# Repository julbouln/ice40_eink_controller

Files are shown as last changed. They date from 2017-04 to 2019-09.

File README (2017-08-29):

FPGA & STM32F0 driven EINK controller

- Final FPGA board: https://oshpark.com/shared_projects/rBoQ8bop
- The links on the Kitnic page make ordering the parts easier: https://kitnic.it/boards/github.com/julbouln/ice40_eink_controller/
- ifusb companion: https://github.com/julbouln/ifusb

Prototype:
- OLIMEX iCE40HX1K-EVB (https://www.olimex.com/Products/FPGA/iCE40/iCE40HX1K-EVB/open-source-hardware)
- NUCLEO-F042K6 (http://www.st.com/content/st_com/en/products/evaluation-tools/product-evaluation-tools/mcu-eval-tools/stm32-mcu-eval-tools/stm32-mcu-nucleo/nucleo-f042k6.html)
- TPS65185EVM (http://www.ti.com/tool/tps65185evm)
- ED060SC7 Kindle 3 EINK screen (http://www.ebay.com/sch/i.html?_from=R40&_trksid=m570.l1313&_nkw=ED060SC7&_sacat=0)
- custom EINK connector board (https://oshpark.com/shared_projects/I7bqOkZB)

Project tree:
- controller/ EINK controller verilog icestorm project
- hardware/ custom ice40 + ED060SC7 connector board
- utils/ misc utilities, including dumper for various reverse engineered waveform file formats
- utils/ifusb/ ifusb host driver

References:
- http://essentialscrap.com/eink/
- http://www.eevblog.com/forum/microcontrollers/interfacing-epd-%28e-ink%29-display-from-kindle-anyone-tried/

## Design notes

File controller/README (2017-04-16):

ice40 eink verilog controller

Notes

Yosys 0.6 needed, because it seems there is a bug related to BRAM with current version https://github.com/cliffordwolf/yosys/issues/335

About performances

Ifusb 12Mhz SPI
1s : 0.25s WRITE + 0.75s DRAW(at 40ns)
0.75s : 0.25s WRITE + 0.50s DRAW(at 20ns)

Full framebuffer write: 800x600/4 = 120000 bytes
At 12Mhz, SPI bandwidth should be around 9Mbs, so theoricaly we should have a write time of ~0.1s but ifusb will introduce latency to SPI because of USB (120000/64 = 1875 bulk packets)

SPI protocol

Command 		Hex		Description
EINK_PING 		0x01	Ping the chip
EINK_STATUS 	0x02	Get current screen status
EINK_WRITE 		0x03	Write data to framebuffer
EINK_DRAW 		0x04	Draw framebuffer to screen
EINK_SET_MODE 	0x05	Set current draw mode

EINK_PING
For testing purpose, simply ping the chip, should return the data send
0x01 0xAA -> 0xAA

EINK_STATUS
Get screen status
0x02 STATUS

Where STATUS is:
bits 7-3: reserved
bits 2-1: current drawing mode (see EINK_SET_MODE)
bit 0: ready or not

EINK_WRITE
Write pixels data to chip framebuffer
0x03 followed by 800x600/4 = 120000 bytes representing pixels in

EINK_DRAW
Actually draw current framebuffer on panel
0x04 0x00

EINK_SET_MODE
Set drawing mode
MODE_CLEAR 	0x00 Clear the screen to white
MODE_DRAW 	0x01 GC4 mode

Waveform hex format

x = color
y = phase

Eink ED06SC7 display signals:
	gmode/mode1: output mode
	cl: source clock
	ckv: gate clock
	spv (start pulse gate): high->low start gate sequence
	sph/xstl (start pulse source): high->low start source sequence
	le (latch enable): low->high load data
	oe (output enable): high->low output data
	d[7:0]: data

source:
     ┌─┐  ┌─┐  ┌─┐  ┌─┐  ┌─┐
cl  ─┘ └──┘ └──┘ └──┘ └──┘ └─ 50ns cycle
    ───┐    ┌────────────────
sph    └────┘
                    ┌─┐           
le  ────────────────┘ └──────
                                                 
d[7:0] __DD___DD___DD___

gate:
     ┌─┐  ┌─┐  ┌─┐  ┌─┐  ┌─┐
ckv ─┘ └──┘ └──┘ └──┘ └──┘ └─ min L 0.5 us
    ──┐    ┌─────────────────
spv   └────┘

References:
http://essentialscrap.com/eink/waveforms.html
http://www.eevblog.com/forum/microcontrollers/interfacing-epd-%28e-ink%29-display-from-kindle-anyone-tried/

TODO
- 20ns operation works, but seems to be a bit buggy
- add SPI command for setting waveform
- 2-bits/4 colors only, must support 4-bits/16 colors (see next point)
- refactor sram/waveform : 

Instead of keeping flipping 2-bits pixel in framebuffer (old pix and new pix) and calculating panel 2-bits signal at drawing step, keep only old framebuffer in 4-bits form in highest part of sram (start at 128k) and calculate 2-bits signal at write step and keep it in lowest part of sram. With this method, we can achieve best performance (20ns operations at drawing), SPI bandwidth being limited by itself (8 cycles for sck 12Mhz) we have more timing room at this step. 

Read the old value from sram, calculate the signal, and write the result to sram should take 4 cycles:
- receive new pixel + set address of old pixel
- read old pixel + set it to waveform calculator
- read calculated result + set address and data to write calculation
- wait data to be writen

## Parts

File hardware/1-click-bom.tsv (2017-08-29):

References | Qty | Description | Manufacturer | MPN | Manufacturer | MPN | Manufacturer | MPN | Manufacturer | MPN | Manufacturer | MPN | Digikey | Mouser | RS | Newark | Farnell
C1, C2, C3, C4 | 4 | 10uF 3216 | KEMET | B45196H2106K109 | AVX | NOSA106M006R0800 | AVX | TAJA106K016RNJ | Vishay | 293D106X9010A2TE3 | AVX | TAJA106K010RNJ | 478-1654-1-ND | 581NOSA106M006R0800 | 4647619 | 65K2813 | 1432318
C11, C22 | 2 | 4.7uF 0603 25V | Murata | GRM188R61E475KE11D | Murata | GRM188R61E475KE15D | Yageo | CC0603KRX5R8BB475 | Murata | GRT188R61E475KE13D | TDK | C1608X5R1E475K080AC | 311-3487-1-ND | 81GRM188R61E475KE1D | 8151386 | 68X2788 | 2672159
C5, C10, C21, C25, C26, C27, C28, C29, C30, C31, C32, C33, C34, C35, C36, C37, C39, C40, C41, C42, C43 | 21 | 100nF 0603 | Yageo | CC0603KRX7R9BB104 | Murata | GRM188R71H104KA93D | Samsung | CL10B104KB8NNNC | AVX | 06033C104KAT2A |  |  | 478-3714-1-ND | 603CC603KRX7R9BB104 | 7235676 | 68R4788 | 1362556
C6, C13, C14 | 3 | 10uF 0805 | Murata | GRM21BR61C106KE15L |  |  |  |  |  |  |  |  | 490-3886-1-ND | 81GRM21BR61C106KE15 | 7236039 | 35R0687 | 1762635
C7, C8, C12, C15, C16, C17, C18, C19, C23, C24 | 10 | 4.7uF 0805 16V | Murata | GRM21BR61E475KA12L |  |  |  |  |  |  |  |  | 490-3335-1-ND | 81GRM21BR61E475KA12 | 7236057 | 24R6340 | 1735529
C9, C20 | 2 | 10nF 0603 | Murata | GRM188R71H103KA01D | Yageo | CC0603KRX7R9BB103 |  |  |  |  | AVX | 0201ZD103KAT2A | 311-1085-6-ND | 81GRM39X103K50D | 2040779 | 38K1669 | 722236RL
D1 | 1 | DIODE SOD-123-2 | MCC | 1N4148W-TP | Diodes Inc. | 1N4148WS-7-F |  |  |  |  |  |  | 1N4148WTPMSCT-ND | 8331N4148WTP | 7384737 | 51T5044 | 1843678
D4, D7 | 2 | MBR130T3G SOD123 | ON Semiconductor | MBR130T3G | Diodes Inc. | B130LAW-7-F |  |  |  |  |  |  | B130LAW-FDICT-ND | 863MBR130T3G | 7815635 | 42K0004 | 1858617
D6, D8 | 2 | BAV99 SOT23 | ON Semiconductor | BAV99LT1G | ON Semiconductor | BAV99LT3G |  |  |  |  |  |  | BAV99LT1GOSCT-ND | 863BAV99LT1G | 1249957 | 10N9382 | 2533389
J1 | 1 | Socket (0.4mm pitch, 34-pin, Ni-barrier) | Panasonic | AXT334124 |  | ED060SC7 |  |  |  |  |  |  | 255-3300-1-ND | 769AXT334124 |  | 29X3301
J2 | 1 | Connector, right angle, surface mount, female, 16 contacts, 2 rows, 2.54mm | Würth Elektronik | 610116249221 |  |  |  |  |  |  |  |  | 732-6082-1-ND | 710610116249221 |  |  | 2470746
L1 | 1 | 4.7uH 20% 1MHz Ferrite 1.1A 1008 | Samsung | CIG22L4R7MNE | Taiyo Yuden | CKP2520V4R7M-T | Murata | LQM2HPN4R7MG0L | Abracon | ASMPH-1008-4R7M-T | Bourns | CVH252009-4R7M | 1276-6213-1-ND | 963CKP2520V4R7MT | 7867131 | 24W0975 | 2118126
L2, L3, L4 | 3 | 2.2uH 20% 1MHz Ferrite 1.3A 1008 | Samsung | CIG22L2R2MNE | NIC Components | NFP1008M2R2TR130F | Murata | LQM2HPN2R2MG0L | Bourns | CVH252009-2R2M |  |  | 1276-6211-1-ND | 652CVH2520092R2M | 7867112 | 24W0973 | 2217694
OSC1 | 1 | 100Mhz 7mm x 5mm | Ecliptek | EC2700TTS-100.000M TR | Ecliptek | EC2700ETTS-100.000M TR | Euroquartz | 3EQHM57-ET-100.000R-C1.5 | Ecliptek | EC2645TTS-100.000M TR | AVX | KC7050A100.000C30E00 | 478-6145-1-ND | 581KC7050A100.0C30 |  | 05N0946 | 1641083
R10 | 1 | 47k5 0603 | Yageo | RC0603FR-0747K5L | Yageo | RT0603FRE0747K5L | Panasonic | ERA-3ARB4752V | TE Connectivity | 8-1614353-4 | TE Connectivity / Neohm | CPF0603B47K5E1 | 311-47.5KHRCT-ND | 603RC0603FR0747K5L | 1228887 | 68R0096 | 2312067
R12 | 1 | 52k3 0603 | Panasonic | ERA3ARB5232V | Yageo | RC0603FR-0752K3L | Vishay Dale | CRCW060352K3FKTA | Panasonic | ERA-3AEB5232V |  |  | P52.3KDBCT-ND | 71CRCW060352.3K | 7088940P | 52K8601 | 2094621
R23, RD5, RD1, RD2, RD3, RD4 | 6 | 0 Ohm 0603 | Vishay | CRCW06030000Z0EAHP | Vishay | CRCW06030000Z0EA | Panasonic | ERJ-3GEY0R00V |  |  |  |  | P0.0GCT-ND | 667ERJ3GEY0R00V | 8206736 | 65T8702 | 1469739
R27 | 1 | 43k 0603 | Panasonic | ERA3APB433V | Vishay | CRCW060343K0FKEA | Panasonic | ERA3AEB433V | Panasonic | ERJP03F4302V | Yageo | RC0603JR-0743KL | 311-43.2KHRDKR-ND | 603RC0603JR0743KL | 6790386 | 52K8524 | 1892846
R3, R5, R6 | 3 | 10k 0603 | Vishay | CRCW060310K0FKEA | Vishay | CRCW060310K0FKEAHP | Panasonic | ERJ-3EKF1002V |  |  |  |  | 311-10.0KHRCT-ND | 71CRCW060310KE3 | 8206742 | 68R2991 | 1469748
R4, R13 | 2 | 22R 0603 | Yageo | RC0603JR-0722RL |  |  |  |  |  |  |  |  | 311-22GRCT-ND | 603RC0603JR0722RL |  | 68R0168 | 9233172
R7 | 1 | 2.2k 0603 1% | Vishay | MCT06030C2201FP500 | Yageo | RC0603FR-072K2L | Panasonic | ERA3AEB222V |  |  |  |  | 311-2.20KHRCT-ND | 603RC0603FR072K2L | 566806P | 68R0064 | 1577611
R9, R11 | 2 | 1M 0603 | Vishay | CRCW06031M00FKEA | Yageo | RC0603FR-071ML | Vishay Dale | CRCW06031M00FKEAHP | Panasonic | ERJ-3EKF1004V |  |  | 541-1.00MHCT-ND | 603RC0603FR071ML | 8206786 | 64R5311 | 1469746
U1 | 1 | TPS65185RSLR | Texas Instruments | TPS65185RSLR | Texas Instruments | TPS65185SRGZR | Texas Instruments | TPS651851RSLT |  |  |  |  | 296-29565-1-ND | 595TPS651851RSLT |  | 87X2294
U2 | 1 |  | Texas Instruments | LM3671MF-1.2/NOPB |  |  |  |  |  |  |  |  | LM3671MF-1.2/NOPBCT-ND | 926LM3671MF1.2NOPB |  | 41K4937 | 1685653
U3 | 1 |  | Texas Instruments | LM3671MF-3.3/NOPB |  |  |  |  |  |  |  |  | LM3671MF-3.3/NOPBCT-ND | 926LM3671MF3.3NOPB | 7615876P | 79K7839 | 1685767
U5 | 1 | SPI FLASH SOIC8 1Mbit | Microchip | SST25VF010A-33-4I-SAE | Microchip | SST25VF010A-33-4C-SAE | Silicon Storage Tech | SST25VF010A |  |  |  |  | SST25VF010A-33-4I-SAE-ND | 80425VF010A3CSAE | 7238726 | 54M1121 | 1368686
U6 | 1 |  | Lattice Semiconductor | ICE40HX1K-VQ100 |  |  |  |  |  |  |  |  | 220-1567-ND | 842ICE40HX1KVQ100 | 7720045P |  | 2362850
U7 | 1 | IS61WV2561 | Samsung | K6R4016V1DND | ISSI | IS61WV25616BLL-10BLI-TR | ISSI | IS61WV25616BLL-10TLI-TR | ISSI | IS61WV25616BLL-10BLI |  |  | 706-1104-ND | 87061WV25616BLL10BLI |  | 55M7806

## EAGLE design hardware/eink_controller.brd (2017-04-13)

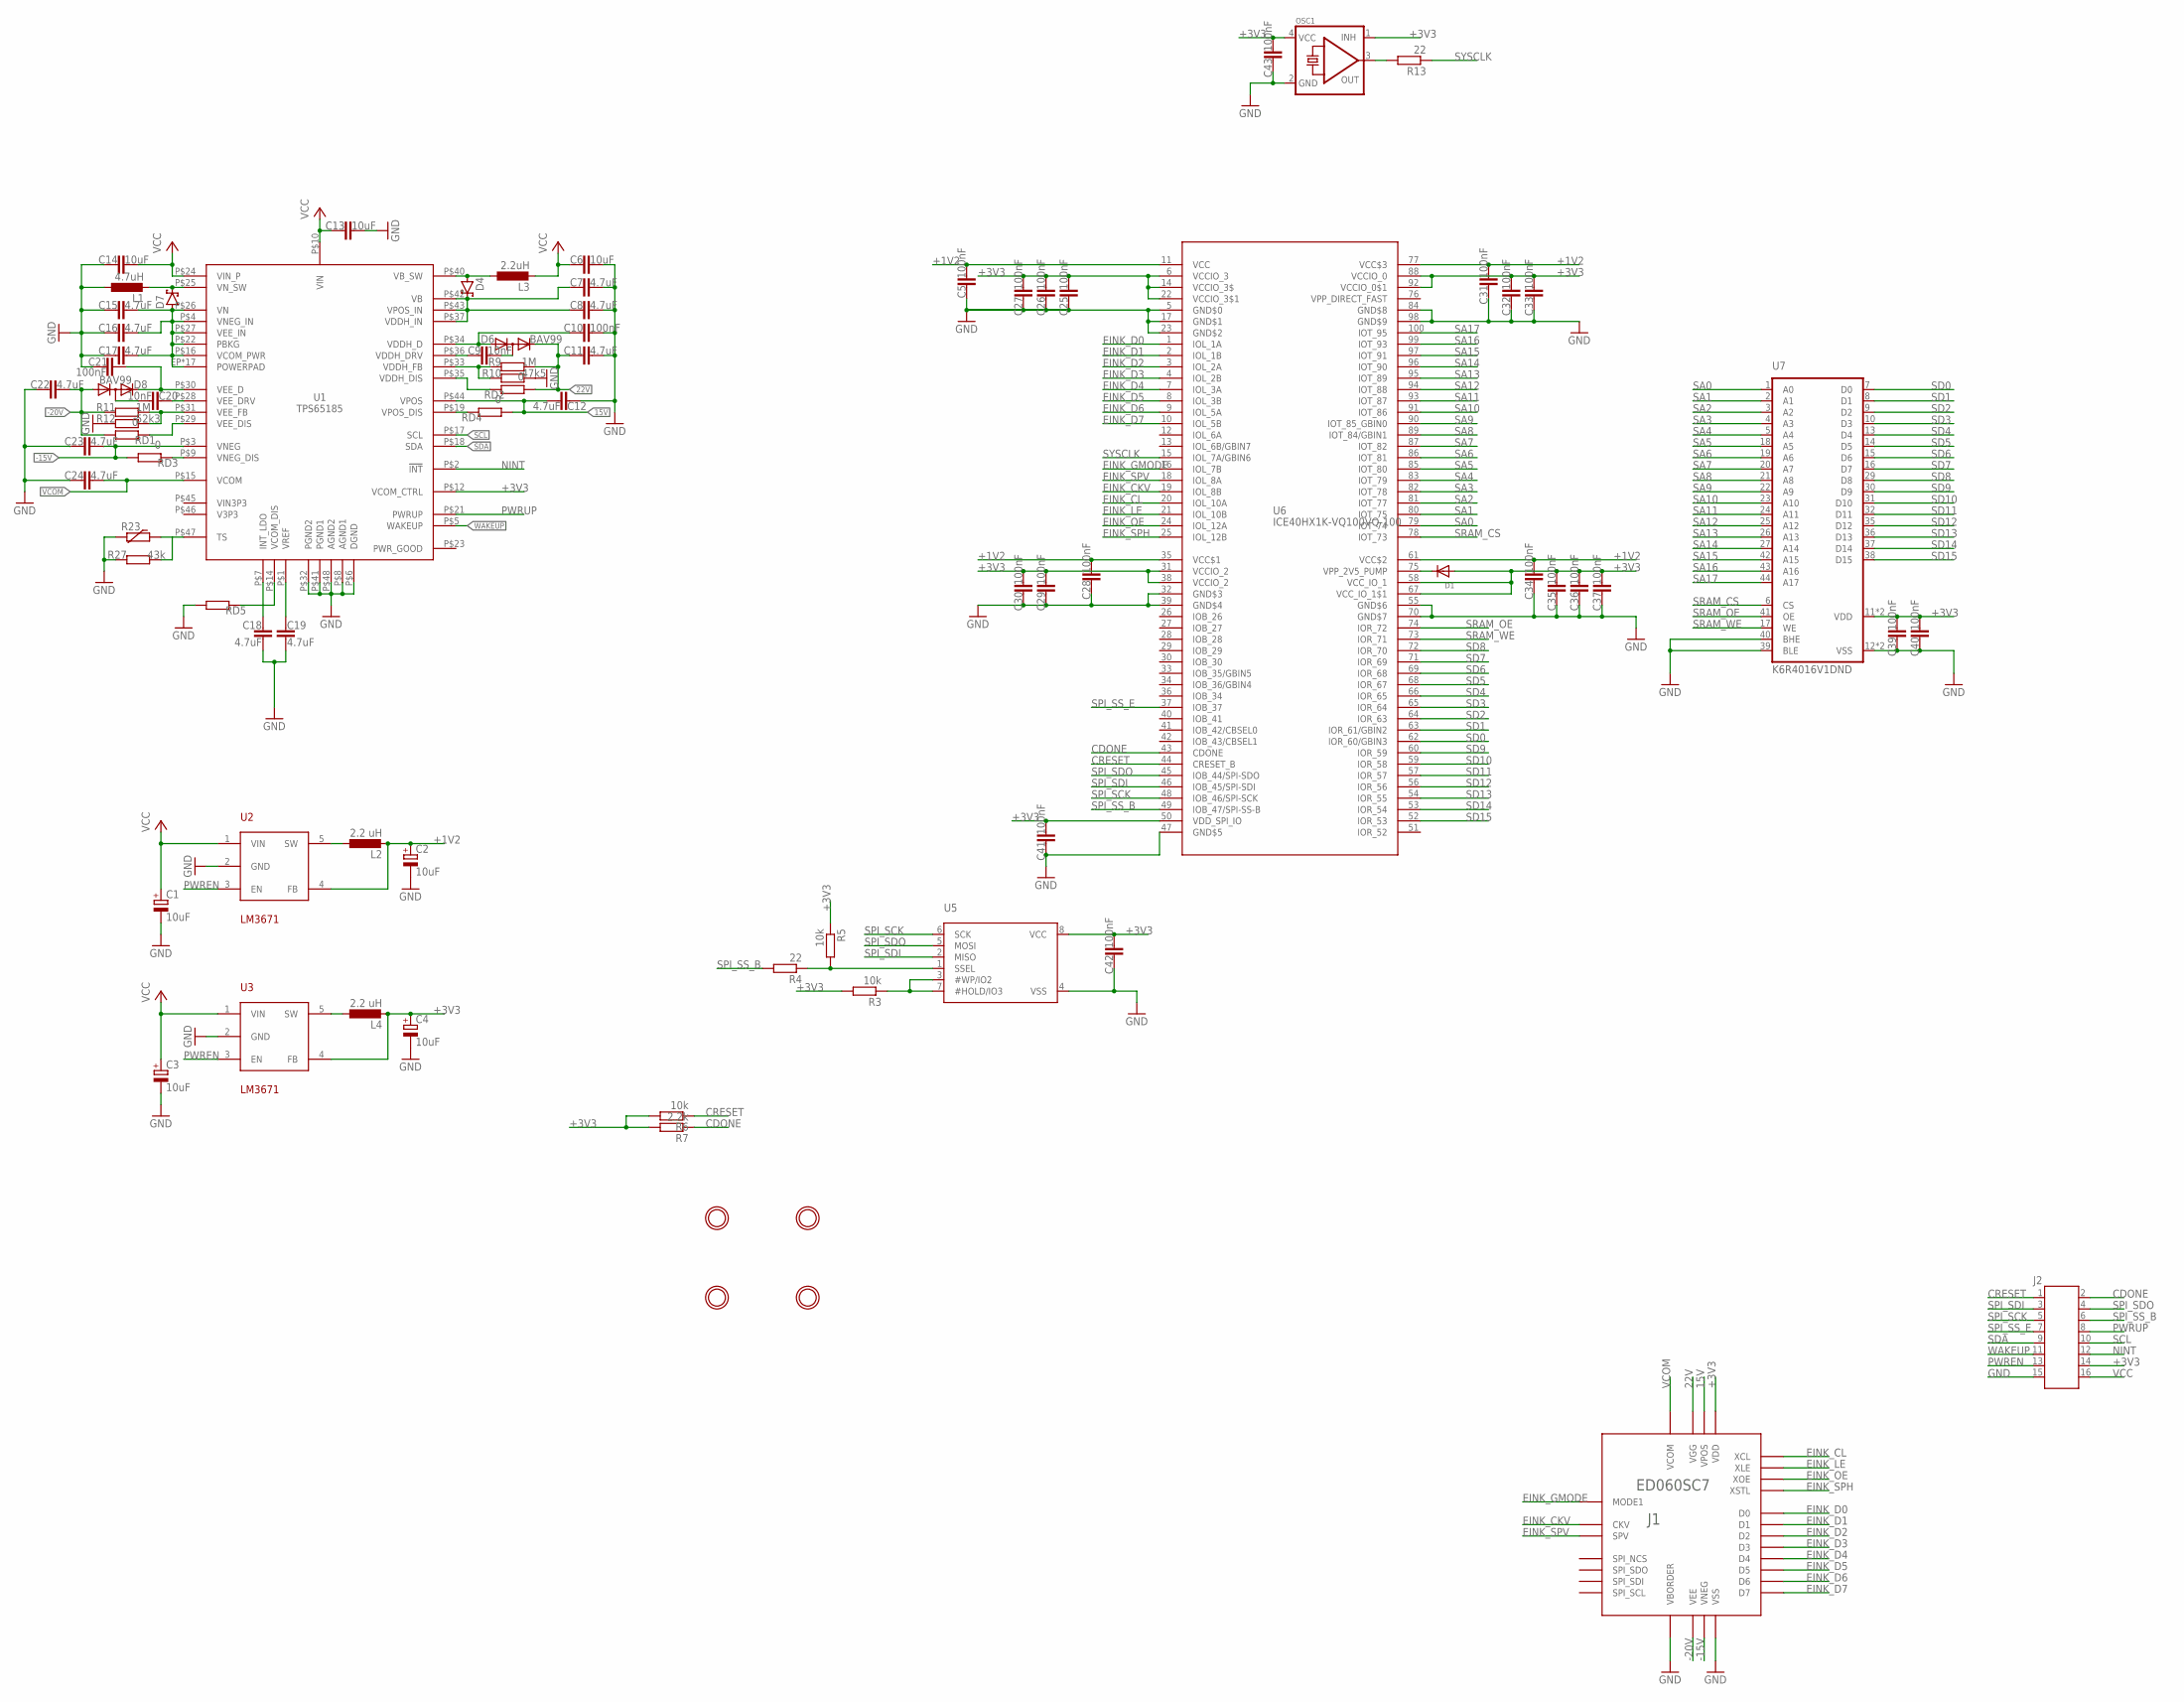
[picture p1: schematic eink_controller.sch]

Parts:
C1, C2, C3, C4: 10uF; A/3216-18R
C5, C10, C21, C25, C26, C27, C28, C29, C30, C31, C32, C33, C34, C35, C36, C37, C39, C40, C41, C42, C43: 100nF; C0603K
C6, C13, C14: 10uF; C0805K
C7, C8, C12, C15, C16, C17, C18, C19, C23, C24: 4.7uF; C0805K
C9, C20: 10nF; C0603K
C11, C22: 4.7uF; C0603K
D1: DIODESOD-123; SOD-123
D4, D7: MBR130T3G; SOD123
D6, D8: BAV99; SOT23
J1: ED060SC7; AXT334124
J2: 610116249221
L1: 4.7uH; L2825P
L2, L4: 2.2 uH; L2825P
L3: 2.2uH; L2825P
OSC1: OSCILLATOR; OSC_7X5MM
R3, R5, R6: 10k; R0603
R4, R13: 22; R0603
R7: 2.2k; R0603
R9, R11: 1M; R0603
R10: 47k5; R0603
R12: 52k3; R0603
R23: R-EU_R0603; R0603
R27: 43k; R0603
RD1, RD2, RD3, RD4: 0; R0603
RD5: R-EU_R0603; R0603
U1: TPS65185; VQFN48
U2, U3: LM3671; SOT23-5
U5: SPIFLASH_SOIC8208MIL; SOIC8_208MIL
U6: ICE40HX1K-VQ100VQ-100; TQFP100
U7: K6R4016V1DND; TSOP44-II
U$1, U$2, U$3, U$4: MOUNTINGHOLE2.0; MOUNTINGHOLE_2.0_PLATED

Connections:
15V: C12.2, J1.P$2 (VPOS), J1.P$4 (VPOS), RD4.1, U1.P$44 (VPOS)
22V: C11.1, D6.2 (C), J1.P$25 (VGG), R9.2, RD2.1
+1V2: C2.+, C5.2, C28.2, C31.2, C34.2, L2.2, U2.4 (FB), U6.11 (VCC), U6.35 (VCC$1), U6.61 (VCC$2), U6.77 (VCC$3)
+3V3: C4.+, C25.2, C26.2, C27.2, C29.2, C30.2, C32.2, C33.2, C35.2, C36.2, C37.2, C39.2, C40.2, C41.2, C42.2, C43.2, D1.A, J1.P$5 (VDD), J1.P$7 (VDD), J2.14, L4.2, OSC1.1 (INH), OSC1.4 (VCC), R3.2, R5.1, R6.2, R7.2, U1.P$12 (VCOM_CTRL), U3.4 (FB), U5.8 (VCC), U6.6 (VCCIO_3), U6.14 (VCCIO_3$), U6.22 (VCCIO_3$1), U6.31 (VCCIO_2), U6.38 (VCCIO_2), U6.50 (VDD_SPI_IO), U6.58 (VCC_IO_1), U6.67 (VCC_IO_1$1), U6.88 (VCCIO_0), U6.92 (VCCIO_0$1), U7.11 (VDD), U7.33 (VDD)
-15V: C23.2, J1.P$1 (VNEG), J1.P$3 (VNEG), RD3.2, U1.P$3 (VNEG)
-20V: C22.2, D8.1 (A), J1.P$27 (VEE), J1.P$29 (VEE), R11.1, RD1.2
CDONE: J2.2, R7.1, U6.43 (CDONE)
CRESET: J2.1, R6.1, U6.44 (CRESET_B)
EINK_CKV: J1.P$28 (CKV), U6.19 (IOL_8B)
EINK_CL: J1.P$9 (XCL), U6.20 (IOL_10A)
EINK_D0: J1.P$13 (D0), U6.1 (IOL_1A)
EINK_D1: J1.P$14 (D1), U6.2 (IOL_1B)
EINK_D2: J1.P$15 (D2), U6.3 (IOL_2A)
EINK_D3: J1.P$16 (D3), U6.4 (IOL_2B)
EINK_D4: J1.P$17 (D4), U6.7 (IOL_3A)
EINK_D5: J1.P$18 (D5), U6.8 (IOL_3B)
EINK_D6: J1.P$19 (D6), U6.9 (IOL_5A)
EINK_D7: J1.P$20 (D7), U6.10 (IOL_5B)
EINK_GMODE: J1.P$26 (MODE1), U6.16 (IOL_7B)
EINK_LE: J1.P$10 (XLE), U6.21 (IOL_10B)
EINK_OE: J1.P$11 (XOE), U6.24 (IOL_12A)
EINK_SPH: J1.P$12 (XSTL), U6.25 (IOL_12B)
EINK_SPV: J1.P$30 (SPV), U6.18 (IOL_8A)
GND: C1.-, C2.-, C3.-, C4.-, C5.1, C6.2, C7.2, C8.2, C10.2, C11.2, C12.1, C13.2, C14.1, C15.1, C16.1, C17.1, C18.1, C19.1, C21.1, C22.1, C23.1, C24.1, C25.1, C26.1, C27.1, C28.1, C29.1, C30.1, C31.1, C32.1, C33.1, C34.1, C35.1, C36.1, C37.1, C39.1, C40.1, C41.1, C42.1, C43.1, J1.P$6 (VSS), J1.P$8 (VSS), J1.P$31 (VSS), J1.P$32 (VBORDER), J2.15, L1.1, OSC1.2 (GND), R10.2, R12.1, R23.1, R27.1, RD5.2, U1.P$6 (DGND), U1.P$8 (AGND1), U1.P$32 (PGND2), U1.P$41 (PGND1), U1.P$48 (AGND2), U2.2 (GND), U3.2 (GND), U5.4 (VSS), U6.5 (GND$0), U6.17 (GND$1), U6.23 (GND$2), U6.32 (GND$3), U6.39 (GND$4), U6.47 (GND$5), U6.55 (GND$6), U6.70 (GND$7), U6.84 (GND$8), U6.98 (GND$9), U7.12 (VSS), U7.34 (VSS), U7.39 (BLE), U7.40 (BHE)
unnamed: RD5.1, U1.P$14 (VCOM_DIS)
unnamed: L4.1, U3.5 (SW)
unnamed: R3.1, U5.3 (#WP/IO2), U5.7 (#HOLD/IO3)
unnamed: OSC1.3 (OUT), R13.2
unnamed: D4.2 (A), L3.1, U1.P$40 (VB_SW)
unnamed: D1.C, U6.75 (VPP_2V5_PUMP)
unnamed: L2.1, U2.5 (SW)
unnamed: R4.1, R5.2, U5.1 (SSEL)
unnamed: C7.1, C8.1, D4.1 (C), U1.P$37 (VDDH_IN), U1.P$42 (VB), U1.P$43 (VPOS_IN)
unnamed: C10.1, D6.1 (A), U1.P$34 (VDDH_D)
unnamed: C9.1, U1.P$36 (VDDH_DRV)
unnamed: C9.2, D6.3 (AC)
unnamed: R9.1, R10.1, U1.P$33 (VDDH_FB)
unnamed: C20.2, D8.3 (AC)
unnamed: D7.1 (C), L1.2, U1.P$25 (VN_SW)
unnamed: C15.2, C16.2, C17.2, D7.2 (A), U1.EP (POWERPAD), U1.EP1 (POWERPAD), U1.EP2 (POWERPAD), U1.EP3 (POWERPAD), U1.EP4 (POWERPAD), U1.EP5 (POWERPAD), U1.EP6 (POWERPAD), U1.EP7 (POWERPAD), U1.EP8 (POWERPAD), U1.EP9 (POWERPAD), U1.EP10 (POWERPAD), U1.EP11 (POWERPAD), U1.EP12 (POWERPAD), U1.EP13 (POWERPAD), U1.EP14 (POWERPAD), U1.EP15 (POWERPAD), U1.EP16 (POWERPAD), U1.P$4 (VNEG_IN), U1.P$16 (VCOM_PWR), U1.P$22 (PBKG), U1.P$26 (VN), U1.P$27 (VEE_IN)
unnamed: C18.2, U1.P$7 (INT_LDO)
unnamed: C19.2, U1.P$1 (VREF)
unnamed: C21.2, D8.2 (C), U1.P$30 (VEE_D)
unnamed: RD3.1, U1.P$9 (VNEG_DIS)
unnamed: C20.1, U1.P$28 (VEE_DRV)
unnamed: R11.2, R12.2, U1.P$31 (VEE_FB)
unnamed: RD1.1, U1.P$29 (VEE_DIS)
unnamed: RD4.2, U1.P$19 (VPOS_DIS)
unnamed: RD2.2, U1.P$35 (VDDH_DIS)
unnamed: R23.2, R27.2, U1.P$47 (TS)
NINT: J2.12, U1.P$2 (!INT)
PWREN: J2.13, U2.3 (EN), U3.3 (EN)
PWRUP: J2.8, U1.P$21 (PWRUP)
SA0: U6.79 (IOT_74), U7.1 (A0)
SA1: U6.80 (IOT_75), U7.2 (A1)
SA2: U6.81 (IOT_77), U7.3 (A2)
SA3: U6.82 (IOT_78), U7.4 (A3)
SA4: U6.83 (IOT_79), U7.5 (A4)
SA5: U6.85 (IOT_80), U7.18 (A5)
SA6: U6.86 (IOT_81), U7.19 (A6)
SA7: U6.87 (IOT_82), U7.20 (A7)
SA8: U6.89 (IOT_84/GBIN1), U7.21 (A8)
SA9: U6.90 (IOT_85_GBIN0), U7.22 (A9)
SA10: U6.91 (IOT_86), U7.23 (A10)
SA11: U6.93 (IOT_87), U7.24 (A11)
SA12: U6.94 (IOT_88), U7.25 (A12)
SA13: U6.95 (IOT_89), U7.26 (A13)
SA14: U6.96 (IOT_90), U7.27 (A14)
SA15: U6.97 (IOT_91), U7.42 (A15)
SA16: U6.99 (IOT_93), U7.43 (A16)
SA17: U6.100 (IOT_95), U7.44 (A17)
SCL: J2.10, U1.P$17 (SCL)
SD0: U6.62 (IOR_60/GBIN3), U7.7 (D0)
SD1: U6.63 (IOR_61/GBIN2), U7.8 (D1)
SD2: U6.64 (IOR_63), U7.9 (D2)
SD3: U6.65 (IOR_64), U7.10 (D3)
SD4: U6.66 (IOR_65), U7.13 (D4)
SD5: U6.68 (IOR_67), U7.14 (D5)
SD6: U6.69 (IOR_68), U7.15 (D6)
SD7: U6.71 (IOR_69), U7.16 (D7)
SD8: U6.72 (IOR_70), U7.29 (D8)
SD9: U6.60 (IOR_59), U7.30 (D9)
SD10: U6.59 (IOR_58), U7.31 (D10)
SD11: U6.57 (IOR_57), U7.32 (D11)
SD12: U6.56 (IOR_56), U7.35 (D12)
SD13: U6.54 (IOR_55), U7.36 (D13)
SD14: U6.53 (IOR_54), U7.37 (D14)
SD15: U6.52 (IOR_53), U7.38 (D15)
SDA: J2.9, U1.P$18 (SDA)
SPI_SCK: J2.5, U5.6 (SCK), U6.48 (IOB_46/SPI-SCK)
SPI_SDI: J2.3, U5.2 (MISO), U6.46 (IOB_45/SPI-SDI)
SPI_SDO: J2.4, U5.5 (MOSI), U6.45 (IOB_44/SPI-SDO)
SPI_SS_B: J2.6, R4.2, U6.49 (IOB_47/SPI-SS-B)
SPI_SS_E: J2.7, U6.37 (IOB_37)
SRAM_CS: U6.78 (IOT_73), U7.6 (CS)
SRAM_OE: U6.74 (IOR_72), U7.41 (OE)
SRAM_WE: U6.73 (IOR_71), U7.17 (WE)
SYSCLK: R13.1, U6.15 (IOL_7A/GBIN6)
VCC: C1.+, C3.+, C6.1, C13.1, C14.2, J2.16, L3.2, U1.P$10 (VIN), U1.P$24 (VIN_P), U2.1 (VIN), U3.1 (VIN)
VCOM: C24.2, J1.P$21 (VCOM), J1.P$23 (VCOM), U1.P$15 (VCOM)
VPP_DIRECT_FAST: U6.76 (VPP_DIRECT_FAST)
WAKEUP: J2.11, U1.P$5 (WAKEUP)

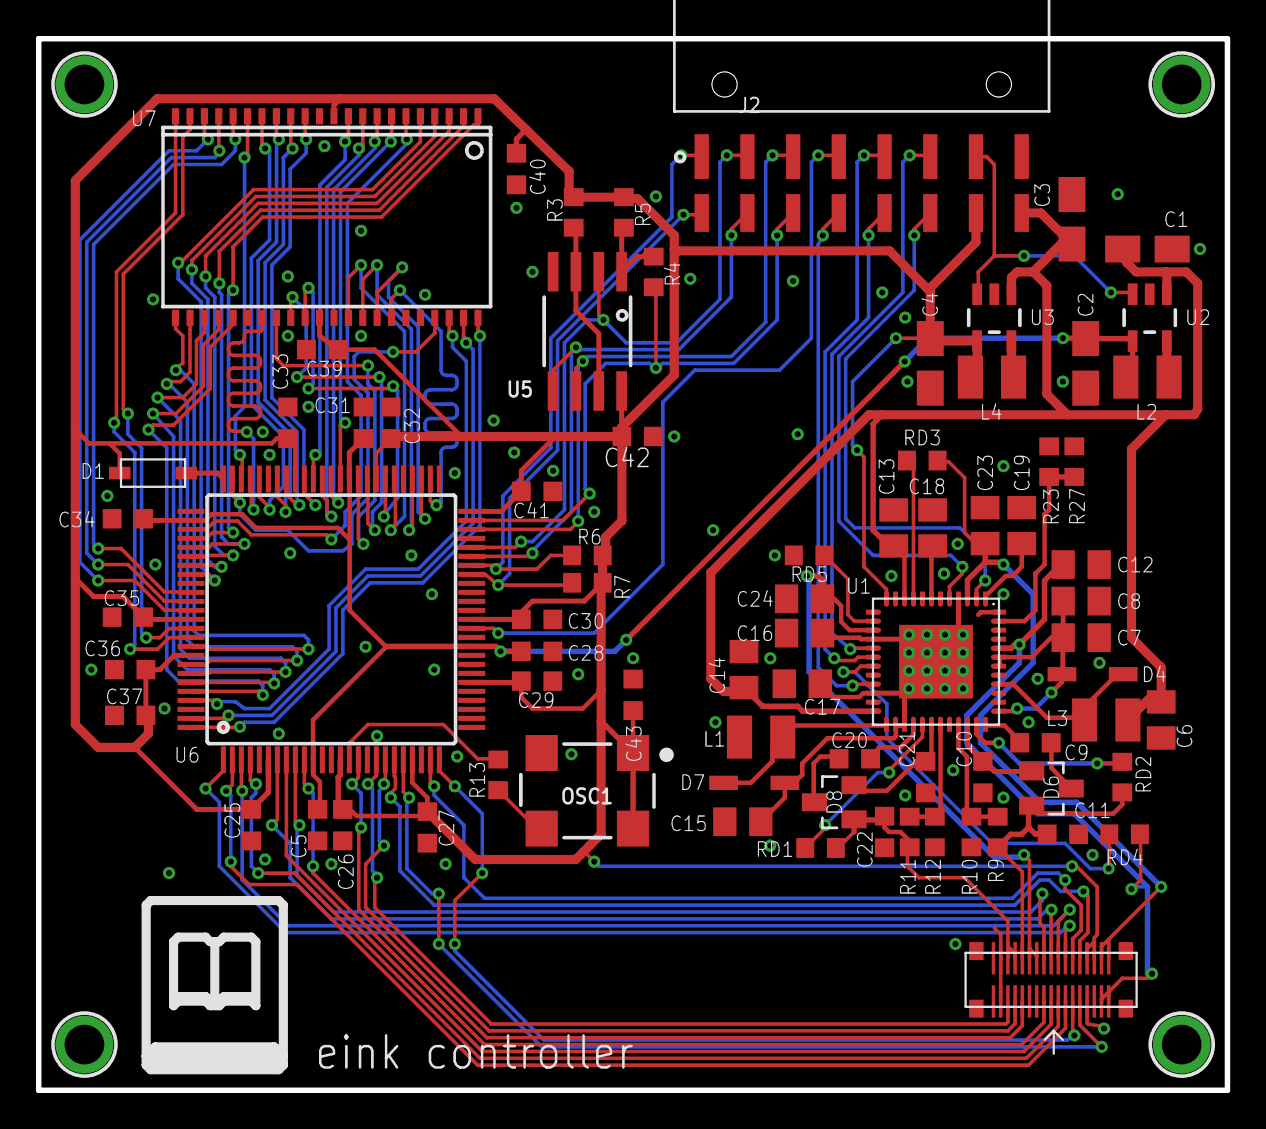
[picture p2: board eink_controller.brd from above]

Board: 2 copper layers, 66.0 x 58.4 mm, 81 parts (0 on the bottom side), 101 nets.

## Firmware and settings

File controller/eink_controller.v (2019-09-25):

`include "spi_slave.v"
`include "asram.v"
`include "ed060sc7.v"

module top(
           input			CLK,
           input			BUT1,
           input			BUT2,
           output			LED1,
           output			LED2,

           input 	  RX,
           output 	  TX,

           output 	  CE_N,
           output 	  WE_N,
           output 	  OE_N,
           inout [15:0]   DQ,
           output [17:0] A,

           output 	  GMODE,
           output 	  SPV,
           output 	  CKV,
           output 	  CL,
           output 	  LE,
           output 	  OE,
           output 	  SPH,
           output [7:0]  DATA,
           input SSEL,
           input SCK,
           input MOSI,
           output MISO
       );

// 100Mhz clock
wire clk = CLK;

reg read_n = 1'b1,
     write_n = 1'b1,
     ce_n = 1'b1;

reg [17:0] address_bus = 0;
reg [15:0] data_bus_in;
wire [15:0] data_bus_out;

wire [7:0] data_bus_out_h = data_bus_out[15:8];
wire [7:0] data_bus_out_l = data_bus_out[7:0];


reg rst = 0;

// bidirectional IO
// https://www.reddit.com/r/yosys/comments/4p8723/iceblink40hx1k_and_yosys/

wire mem_out_en = ~write_n;
wire [15:0] mem_out;
wire [15:0] mem_in;

SB_IO #(
          .PIN_TYPE(6'b 1010_01),
          .PULLUP(1'b 0)
      ) mem_io [15:0] (
          .PACKAGE_PIN(DQ),
          .OUTPUT_ENABLE(mem_out_en),
          .D_OUT_0(mem_out),
          .D_IN_0(mem_in)
      );

wire [17:0] address;

// SPI interface

reg start = 1'b0;
wire ready;
reg [1:0] mode = 1;

parameter SPI_CMD_NONE = 3'h00;
parameter SPI_CMD_PING = 3'h01;
parameter SPI_CMD_STATUS = 3'h02;
parameter SPI_CMD_WRITE = 3'h03;
parameter SPI_CMD_DRAW = 3'h04;
parameter SPI_CMD_SET_MODE = 3'h05;
parameter SPI_CMD_CLEAR_CLIP = 3'h06;
parameter SPI_CMD_SET_CLIP = 3'h07;

wire [7:0] spi_rx_byte;
reg [7:0] spi_tx_byte = 8'h0;
wire spi_received;
reg spi_incoming = 0;
reg spi_first_byte = 0;
reg [2:0] spi_bytes_count = 0;
wire spi_start_message;
wire spi_end_message;

reg [2:0] spi_cmd = SPI_CMD_NONE;

reg [7:0] data_out_r = 0;

reg swap = 0;

reg clip=0;

reg [7:0] clip_x1 = 0;
reg [7:0] clip_x2 = 200;

reg [9:0] clip_y1 = 0;
reg [9:0] clip_y2 = 600;

parameter SPI_CLIP_X1 = 2;
parameter SPI_CLIP_X2 = 3;
parameter SPI_CLIP_Y1_H = 4;
parameter SPI_CLIP_Y1_L = 5;
parameter SPI_CLIP_Y2_H = 6;
parameter SPI_CLIP_Y2_L = 7;

spi_slave spi(clk,
              spi_rx_byte,
              spi_tx_byte,
              spi_received,
              spi_start_message,
              spi_end_message,

              SCK,
              MOSI,
              MISO,
              SSEL
             );

parameter WRITE_IDLE = 0;
parameter WRITE_START = 1;
parameter WRITE_FLIP = 2;
parameter WRITE_DONE = 3;

reg [2:0] write_state = WRITE_IDLE;
reg [1:0] wait_flip = 0;

always @(posedge clk) begin
    if(ready) begin // waiting for new command
        if(spi_start_message) begin // new SPI command received
            spi_first_byte <= 1'b1;
            spi_bytes_count <= 1;
        end else begin
            if(spi_received) begin // new SPI data received
                if(spi_bytes_count==1) begin // first byte is command
                    spi_tx_byte <= 8'h0;
                    spi_cmd <= spi_rx_byte[2:0];
                    spi_first_byte <= 1'b0;
                    spi_bytes_count <= spi_bytes_count+1;
                    address_bus <= 0;
                end else begin // other bytes are command's data
                    case(spi_cmd)
                        SPI_CMD_WRITE: begin
                            write_state <= WRITE_START;
                            spi_bytes_count <= 0;
                        end                        
                        SPI_CMD_PING: begin
                            spi_tx_byte <= spi_rx_byte;
                            spi_bytes_count <= 0;
                        end
                        SPI_CMD_DRAW: begin
                            start <= 1;
                            spi_bytes_count <= 0;
                        end
                        SPI_CMD_SET_MODE: begin
                            mode <= spi_rx_byte;
                            spi_bytes_count <= 0;
                        end
                        SPI_CMD_STATUS: begin
                            spi_tx_byte <= {5'h0,mode,ready};
                            spi_bytes_count <= 0;
                        end
                        SPI_CMD_CLEAR_CLIP: begin
                            clip <= 0;
                            spi_bytes_count <= 0;
                        end
                        SPI_CMD_SET_CLIP: begin
                          case(spi_bytes_count)
                            SPI_CLIP_X1: begin
                              clip_x1 <= spi_rx_byte;
                            end
                            SPI_CLIP_X2: begin
                              clip_x2 <= spi_rx_byte;
                            end
                            SPI_CLIP_Y1_H: begin
                              clip_y1[9:8] <= spi_rx_byte[1:0];
                            end
                            SPI_CLIP_Y1_L: begin
                              clip_y1[7:0] <= spi_rx_byte;
                            end
                            SPI_CLIP_Y2_H: begin
                              clip_y2[9:8] <= spi_rx_byte[1:0];
                            end
                            SPI_CLIP_Y2_L: begin
                              clip_y2[7:0] <= spi_rx_byte;
                            end
                            default: begin
                            end
                          endcase
                          if(spi_bytes_count < SPI_CLIP_Y2_L) begin
                            spi_bytes_count <= spi_bytes_count+1;
                          end else begin
                            clip <= 1;
                            spi_bytes_count <= 0;
                          end
                        end
                        default: begin
                            spi_bytes_count <= 0;
                            // unknown command
                        end
                    endcase
                end
            end else begin              
              // keep previous pixel value
              case(write_state) 
              WRITE_IDLE: begin
                // disable memory access
                write_n <= 1'b1;
                read_n <= 1'b1;
                ce_n <= 1'b1;
              end
              WRITE_START: begin
                // keep previous data 
                address_bus <= address_bus + 1;
                write_n <= 1'b1;
                read_n <= 1'b0;
                ce_n <= 1'b0;
                write_state <= WRITE_FLIP;
              end
              WRITE_FLIP: begin
                // data_bus_out_prev <= data_bus_out;
                // wait memory read
                wait_flip <= wait_flip + 1;           
                if(wait_flip == 3) begin
                  data_out_r <= data_bus_out_l;
                  write_state <= WRITE_DONE;
                end
              end
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

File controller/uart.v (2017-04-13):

`timescale 1ns / 1ps
// Documented Verilog UART
// Copyright (C) 2010 Timothy Goddard (tim@goddard.net.nz)
//               2013 Aaron Dahlen
// Distributed under the MIT licence.
//
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
//** INSTANTIATION ********************************************
//
//  To instantiate this module copy this section to your main code...
//
//    uart #(
//        .baud_rate(baud_rate),            // default is 9600
//        .sys_clk_freq(sys_clk_freq)       // default is 100000000
//     )
//    instance_name(
//        .clk(clk),                        // The master clock for this module
//        .rst(rst),                        // Synchronous reset
//        .rx(rx),                          // Incoming serial line
//        .tx(tx),                          // Outgoing serial line
//        .transmit(transmit),              // Signal to transmit
//        .tx_byte(tx_byte),                // Byte to transmit
//        .received(received),              // Indicated that a byte has been received
//        .rx_byte(rx_byte),                // Byte received
//        .is_receiving(is_receiving),      // Low when receive line is idle
//        .is_transmitting(is_transmitting),// Low when transmit line is idle
//        .recv_error(recv_error)           // Indicates error in receiving packet.
//      //.recv_state(recv_state),          // for test bench
//      //.tx_state(tx_state)               // for test bench
//    );
//

module uart(
           input clk,                  // The master clock for this module
           input rst,                  // Synchronous reset
           input rx,                   // Incoming serial line
           output tx,                  // Outgoing serial line
           input transmit,             // Assert to begin transmission
           input [7:0] tx_byte,        // Byte to transmit
           output received,            // Indicates that a byte has been received
           output [7:0] rx_byte,       // Byte received
           output wire is_receiving,   // Low when receive line is idle.
           output wire is_transmitting,// Low when transmit line is idle.
           output wire recv_error,      // Indicates error in receiving packet.
           output reg [3:0] rx_samples,
           output reg [3:0] rx_sample_countdown
       );

// The clock_divider is calculated using baud_rate and sys_clk_freq.
// To modify baud rate you can modify the defaults shown below or instantiate
// the module using the template shown in the INSTANTIATION section above.
// For aditional information about instantiation please see:
// http://www.sunburst-design.com/papers/CummingsHDLCON2002_Parameters_rev1_2.pdf

parameter baud_rate = 9600;
parameter sys_clk_freq = 100000000;

localparam one_baud_cnt = sys_clk_freq / (baud_rate);

//** SYMBOLIC STATE DECLARATIONS ******************************

localparam [2:0]
           RX_IDLE             = 3'd0,
           RX_CHECK_START      = 3'd1,
           RX_SAMPLE_BITS      = 3'd2,
           RX_READ_BITS        = 3'd3,
           RX_CHECK_STOP       = 3'd4,
           RX_DELAY_RESTART    = 3'd5,
           RX_ERROR            = 3'd6,
           RX_RECEIVED         = 3'd7;

localparam [1:0]
           TX_IDLE             = 2'd0,
           TX_SENDING          = 2'd1,
           TX_DELAY_RESTART    = 2'd2,
           TX_RECOVER          = 2'd3;


//** SIGNAL DECLARATIONS **************************************

reg [log2(one_baud_cnt * 16)-1:0] rx_clk;
reg [log2(one_baud_cnt)-1:0] tx_clk;

reg [2:0] recv_state = RX_IDLE;
reg [3:0] rx_bits_remaining;
reg [7:0] rx_data;

reg tx_out = 1'b1;
reg [1:0] tx_state = TX_IDLE;
reg [3:0] tx_bits_remaining;
reg [7:0] tx_data;


//** ASSIGN STATEMENTS ****************************************

assign received = recv_state == RX_RECEIVED;
assign recv_error = recv_state == RX_ERROR;
assign is_receiving = recv_state != RX_IDLE;
assign rx_byte = rx_data;

assign tx = tx_out;
assign is_transmitting = tx_state != TX_IDLE;


//** TASKS / FUNCTIONS ****************************************

function integer log2(input integer M);
    integer i;
    begin
        log2 = 1;
        for (i = 0; 2**i <= M; i = i + 1)
            log2 = i + 1;
    end endfunction


//** Body *****************************************************

always @(posedge clk) begin
    if (rst) begin
        recv_state = RX_IDLE;
        tx_state = TX_IDLE;
    end

    // Countdown timers for the receiving and transmitting
    // state machines are decremented.

    if(rx_clk) begin
        rx_clk = rx_clk - 1'd1;
    end

    if(tx_clk) begin
        tx_clk = tx_clk - 1'd1;
    end


    //** Receive state machine ************************************

    case (recv_state)
        RX_IDLE: begin
            // A low pulse on the receive line indicates the
            // start of data.
            if (!rx) begin
                // Wait 1/2 of the bit period
                rx_clk = one_baud_cnt / 2;
                recv_state = RX_CHECK_START;
            end
        end

        RX_CHECK_START: begin
            if (!rx_clk) begin
                // Check the pulse is still there
                if (!rx) begin
                    // Pulse still there - good
                    // Wait the bit period plus 3/8 of the next
                    rx_clk = (one_baud_cnt / 2) + (one_baud_cnt * 3) / 8;
                    rx_bits_remaining = 8;
                    recv_state = RX_SAMPLE_BITS;
                    rx_samples = 0;
                    rx_sample_countdown = 5;
                end else begin
                    // Pulse lasted less than half the period -
                    // not a valid transmission.
                    recv_state = RX_ERROR;
                end
            end
        end

        RX_SAMPLE_BITS: begin
            // sample the rx line multiple times
            if (!rx_clk) begin
                if (rx) begin
                    rx_samples =  rx_samples + 1'd1;
                end
                rx_clk = one_baud_cnt / 8;
                rx_sample_countdown = rx_sample_countdown -1'd1;
                recv_state = rx_sample_countdown ? RX_SAMPLE_BITS : RX_READ_BITS;
            end
        end

        RX_READ_BITS: begin
            if (!rx_clk) begin
                // Should be finished sampling the pulse here.
                // Update and prep for next
                if (rx_samples > 3) begin
                    rx_data = {1'd1, rx_data[7:1]};
                end else begin
                    rx_data = {1'd0, rx_data[7:1]};
                end

                rx_clk = (one_baud_cnt * 3) / 8;
                rx_samples = 0;
                rx_sample_countdown = 5;
                rx_bits_remaining = rx_bits_remaining - 1'd1;
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

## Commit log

2017-04-17 add DU mode + fix wbf dump
    [eink.c]
2017-08-24 Make compatible with kitnic.it
    [1-click-bom.tsv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]
2017-08-24 Improve retailer part selection a bit
    [1-click-bom.tsv]
2017-08-29 Fix BOM errors and improve part selection
    [1-click-bom.tsv]

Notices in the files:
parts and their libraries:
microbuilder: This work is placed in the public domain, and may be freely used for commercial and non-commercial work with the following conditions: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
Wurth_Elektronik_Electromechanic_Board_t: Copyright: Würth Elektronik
